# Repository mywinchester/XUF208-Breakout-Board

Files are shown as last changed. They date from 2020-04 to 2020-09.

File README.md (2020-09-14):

# XMOS XU(F)208 Breakout Board <!-- omit in toc -->

XMOS XU208/XUF208 series minimal system board with USB Type-C port, full XSYS debug port, all pin already breakout to edge of the board.

#### Table of Contents <!-- omit in toc -->

- [1. Image](#1-image)
- [2. Altium Libraries](#2-altium-libraries)
- [3. Shield](#3-shield)
- [4. About fabrication files](#4-about-fabrication-files)
  - [4.1. Gerber files](#41-gerber-files)
  - [4.2. NC drill files](#42-nc-drill-files)
- [5. Last](#5-last)

## 1. Image

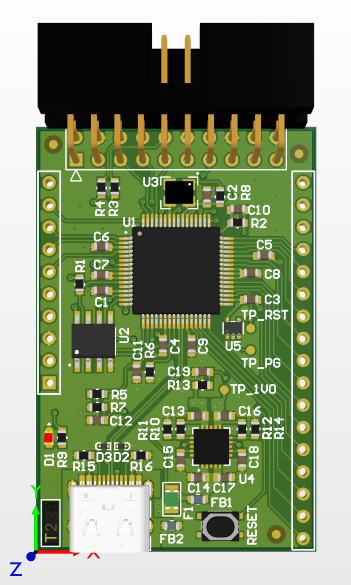
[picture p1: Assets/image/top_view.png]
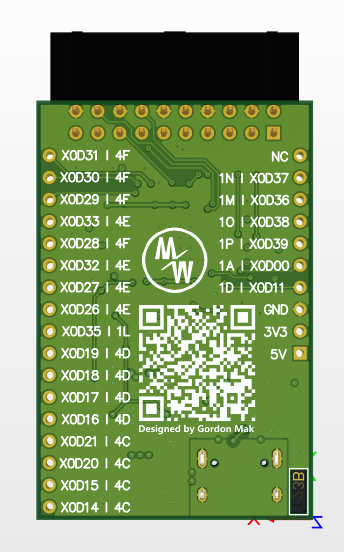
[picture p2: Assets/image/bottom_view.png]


## 2. Altium Libraries

All using components from [Altium-Components-Libraries](https://github.com/mywinchester/Altium-Components-Libraries), this is an open source project focus on refined component management. Classified components with 3D model, easy to use schematic with different package, and also using official recommended layout.

## 3. Shield

Now we have two shield for this breakout board:

- [XUF208-Clock-Board](https://github.com/mywinchester/XUF208-Clock-Board) : Clock generated board with CDCE913 PLL, with I2C interface. Clock output from Y1 pin.

- [XUF208-IO-Board](https://github.com/mywinchester/XUF208-IO-Board) : Four LEDs and four buttons board.

And there have a table for complete plan:

| XUF208-Breakout-Board | XUF208-Clock-Board | XUF208-DAC-Board | XUF208-ADC-Board | XUF208-SPDIF-Board | XUF208-IO-Board |
| :--- | :--- | :--- | :--- | :--- | :--- |
| X0D31(4F) | | | | | |
| X0D30(4F) | | | | | |
| X0D29(4F) | | | | | |
| X0D33(4E) | | | | | |
| X0D28(4F) | -> I2C_SCL | -> I2C_SCL | -> I2C_SCL | | |
| X0D32(4E) | | | | | |
| X0D27(4E) | | | | | |
| X0D26(4E) | <-> I2C_SDA | <-> I2C_SDA | <-> I2C_SDA | | |
| X0D35(1L) | <- MCLK | -> MCLK | -> MCLK | -> MCLK | |
| X0D19(4D) | | | | | <- BUTTON_1 |
| X0D18(4D) | | | | | <- BUTTON_2 |
| X0D17(4D) | | | | | <- BUTTON_3 |
| X0D16(4D) | | | | | <- BUTTON_4 |
| X0D21(4C) | | | | | -> LED_1 |
| X0D20(4C) | | | | | -> LED_2 |
| X0D15(4C) | | | | | -> LED_3 |
| X0D14(4C) | | | | | -> LED_4 |
| - | - | - | - | - | - |
| X0D37(1N) | | -> LRCLK | -> LRCLK | | |
| X0D36(1M) | | -> BCLK | -> BCLK | | |
| X0D38(1O) | | -> DIN | | | |
| X0D39(1P) | | | <-DOUT | | |
| X0D00(1A) | | | | <- S/PDIF_RX | |
| X0D11(1D) | | | | -> S/PDIF_TX | |

Note:

> ` -> ` means Input (for shield itself)  
> ` <- ` means Output (for shield itself)  
> ` <-> ` means Bidirectional (for shield itself)  
> ` - ` means Placeholder

## 4. About fabrication files

Folder Gerber include **gerber files** and **NC drill files**. If your manufacturer using other format or setting for fabrication files, you should not be use those files.

### 4.1. Gerber files

Exported with following settings:

- Unit: Inches
- Format: 2:5
- Output Layout: Plot all layers, except:
  - Mechanical 13
  - Mechanical 15
  - Mechanical 16
  - Top Pad Master
  - Buttom Pad Master
- Plot all used drill pairs
- Use software arcs
- other setting use default

Note:

> `Mechanical 1`(Gerber/XUF208_Breakout.GM1) for board shape.  
> `Mechanical 17`(Gerber/XUF208_Breakout.GM17) for describe impedance detail.

### 4.2. NC drill files

Exported with following settings:

- default

## 5. Last

Have fun with it :)

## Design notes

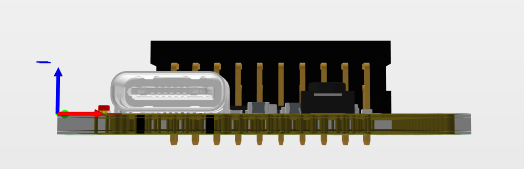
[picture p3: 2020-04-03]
Assets/image/front_view.png

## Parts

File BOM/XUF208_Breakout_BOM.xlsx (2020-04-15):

Quantity | Designator | Value | Description | Comment | LibRef | Footprint | Manufacturer Part Number
12 | C1, C2, C3, C4, C5, C6, C7, C8, C9, C10, C11, C19 | 100nF | Multilayer Ceramic Capacitors | MLCC | MLCC | CAP_0603 | CL10B104KB8NNNC
1 | C12 | 1uF | Multilayer Ceramic Capacitors | MLCC | MLCC | CAP_0603 | CL10A105KB8NNNC
4 | C13, C14, C16, C17 | 10uF | Multilayer Ceramic Capacitors | MLCC | MLCC | CAP_0603 | CL10A106MQ8NNNC
2 | C15, C18 | 10nF | Multilayer Ceramic Capacitors | MLCC | MLCC | CAP_0603 | CL10B103KB8NNNC
1 | D1 |  | LED Emitters | LED | LED | 0603_RED | 19-217/R6C-AL1M2VY/3T
2 | D2, D3 |  | ESD Protection Diode | ESD9B | ESD9B | SOD-923-2 | ESD9B5.0ST5G
1 | F1 |  | Fuses | Fuse | Fuse | 0805 | 0805L110SLYR
1 | FB1 | 300Ohms @ 100MHz | Ferrite Beads | Ferrite | Ferrite | IND_1608 | MMZ1608R301ATA00
1 | FB2 | 47Ohms @ 100MHz | Ferrite Beads | Ferrite | Ferrite | IND_1608 | BLM18BB470SN1D
1 | J1 |  | Universal Serial Bus (USB) I/O Receptacle, Type C, 2.0 | USB C RECEPTACLE(1) | USB C RECEPTACLE(1) | USB C RECEPTACLE 2(1) | TYPE-C-31-M-12
1 | J2 |  | 20-Pin Shrouded Header (IDC) Right Angle | DC3-20P | DC3-20P | IDC-20 (1) | Z-231012020106
1 | P1 |  | Header, 10-Pin | Header 10 | Header 10 | HDR1X10
1 | P2 |  | Header, 17-Pin | Header 17 | Header 17 | HDR1X17
1 | R1 | 1K | Chip Resistors | RES | RES | RC0603N | AC0603FR-071KL
1 | R2 | 4.7 | Chip Resistors | RES | RES | RC0603N | RC0603JR-074R7L
2 | R3, R4 | 33 | Chip Resistors | RES | RES | RC0603N | RC0603FR-0733RL
3 | R5, R8, R13 | 10K | Chip Resistors | RES | RES | RC0603N | RC0603FR-0710KL
1 | R6 | 43.2 | Chip Resistors | RES | RES | RC0603N | RC0603FR-0743R2L
1 | R7 | 47K | Chip Resistors | RES | RES | RC0603N | RC0603FR-0747KL
1 | R9 | 2K | Chip Resistors | RES | RES | RC0603N | RC0603FR-072KL
1 | R10 | 33.2K | Chip Resistors | RES | RES | RC0603N | RC0603FR-0733K2L
1 | R11 | 10.7K | Chip Resistors | RES | RES | RC0603N | AC0603FR-0710K7L
1 | R12 | 2.55K | Chip Resistors | RES | RES | RC0603N | AC0603FR-072K55L
1 | R14 | 10.2K | Chip Resistors | RES | RES | RC0603N | AC0603FR-0710K2L
2 | R15, R16 | 5.1K | Chip Resistors | RES | RES | RC0603N | RC0603FR-075K1L
1 | RESET1 |  | Switch | Tact Switch SPST | Tact Switch SPST | TS_SPST_W4.2XD3.2 | SKRPABE010
1 | U1 |  | xCORE Multicore Microcontroller, xCORE-200, USB, Single Tile, 8 Cores, 500MHz, 64TQFP | XUF208-256-TQ64 | XUF208-256-TQ64 | TQ64 | XUF208-256-TQ64
1 | U2 |  | 3V 16M-BIT SERIAL FLASH MEMORY WITH DUAL/QUAD SPI | W25Q16JV | W25Q16JV | SOIC-8_150MIL | W25Q16JVSNIQ
1 | U3 |  | SiTime Ultra Performance Oscillator | XO | XO | QFN_3225_4P | SiT8008AI-21-33N-24.000000D
1 | U4 |  | TPS7A87 Dual, 500-mA, Low-Noise (3.8 μVRMS), LDO Voltage Regulator | TPS7A87 | TPS7A87 | RTJ20 | TPS7A8701RTJT
1 | U5 |  | Single 2-Input AND Gate | MC74VHC1G08 | MC74VHC1G08 | SC-88A | MC74VHC1G08DFT1G

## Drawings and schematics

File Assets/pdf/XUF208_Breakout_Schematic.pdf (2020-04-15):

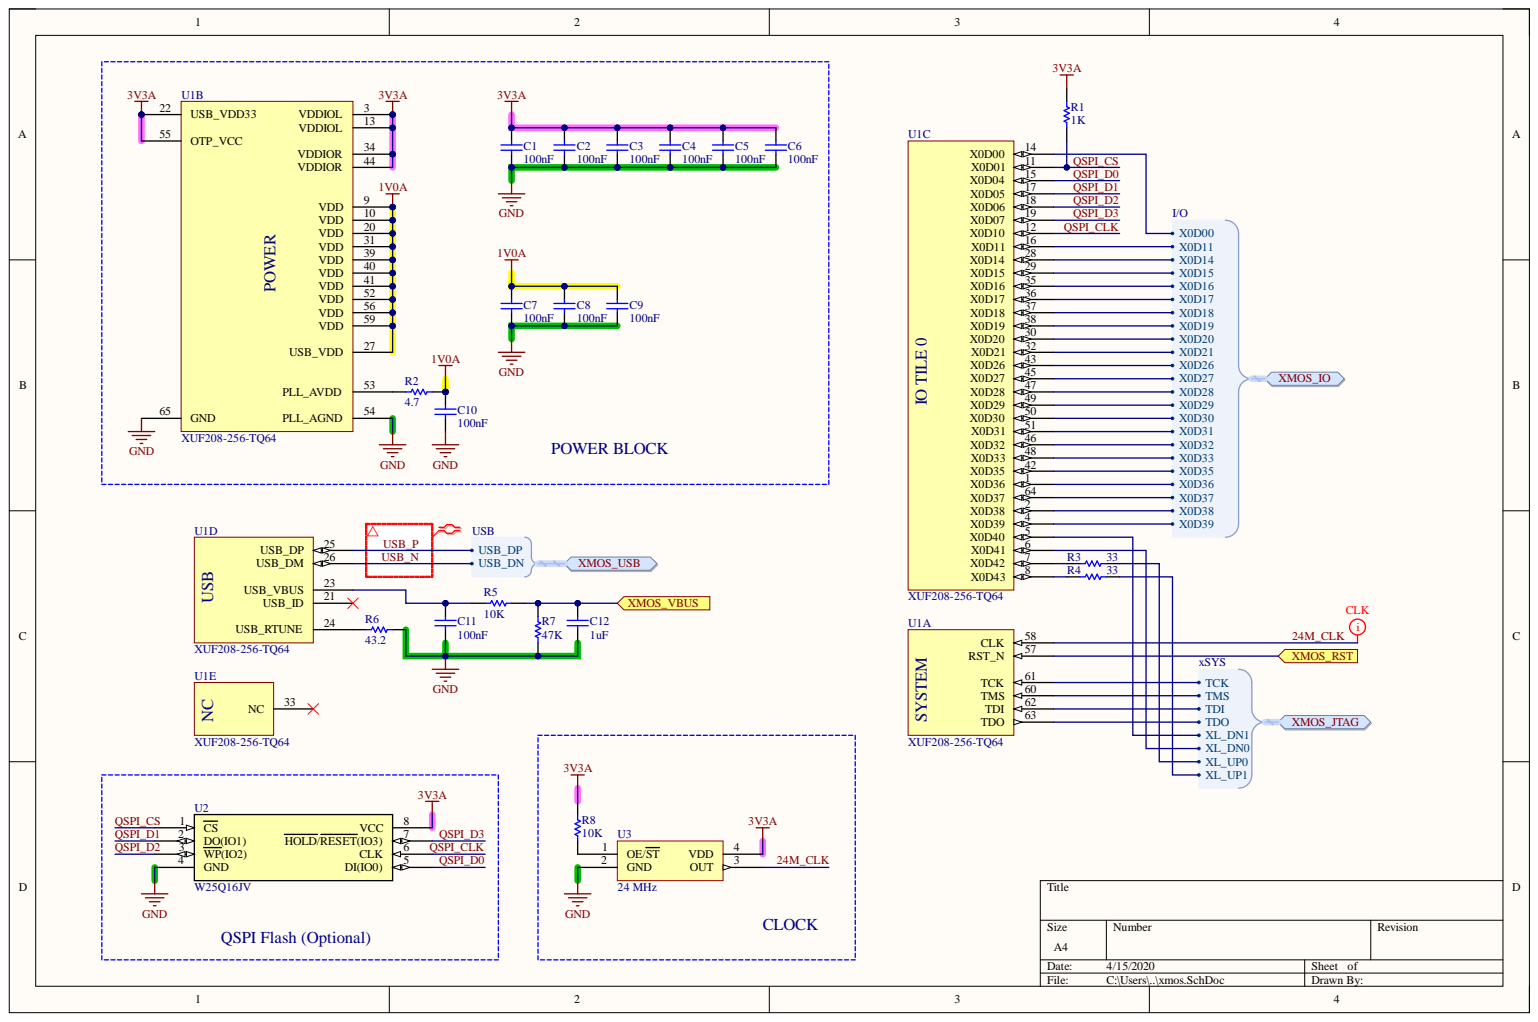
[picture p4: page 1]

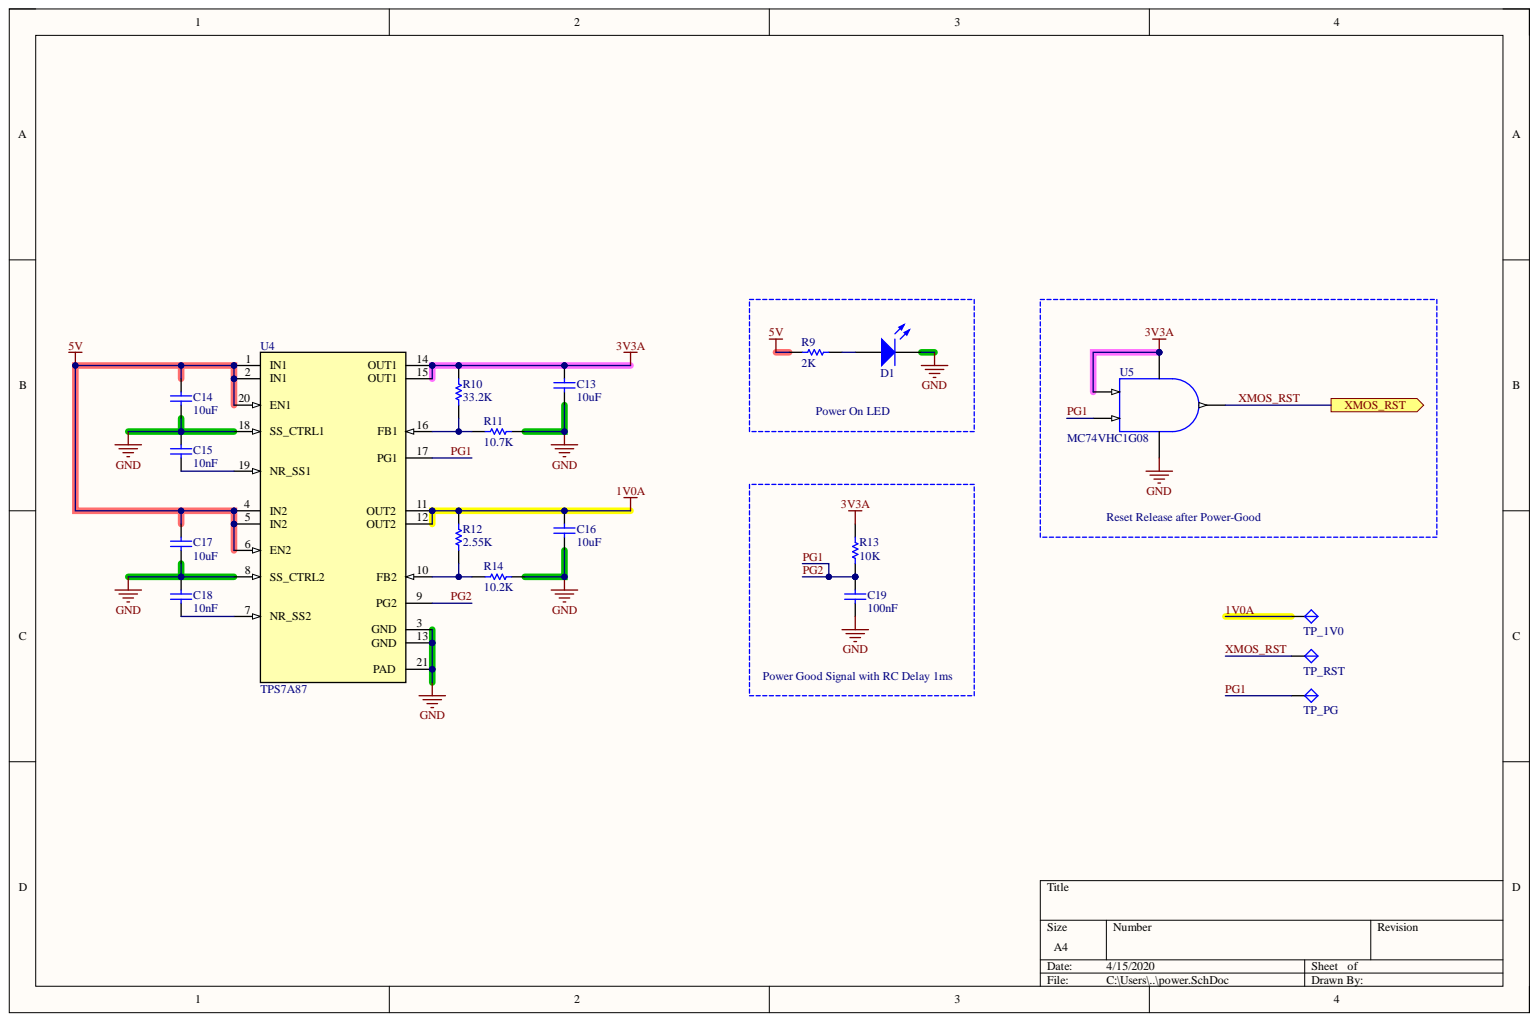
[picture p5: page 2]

Reset Release after Po

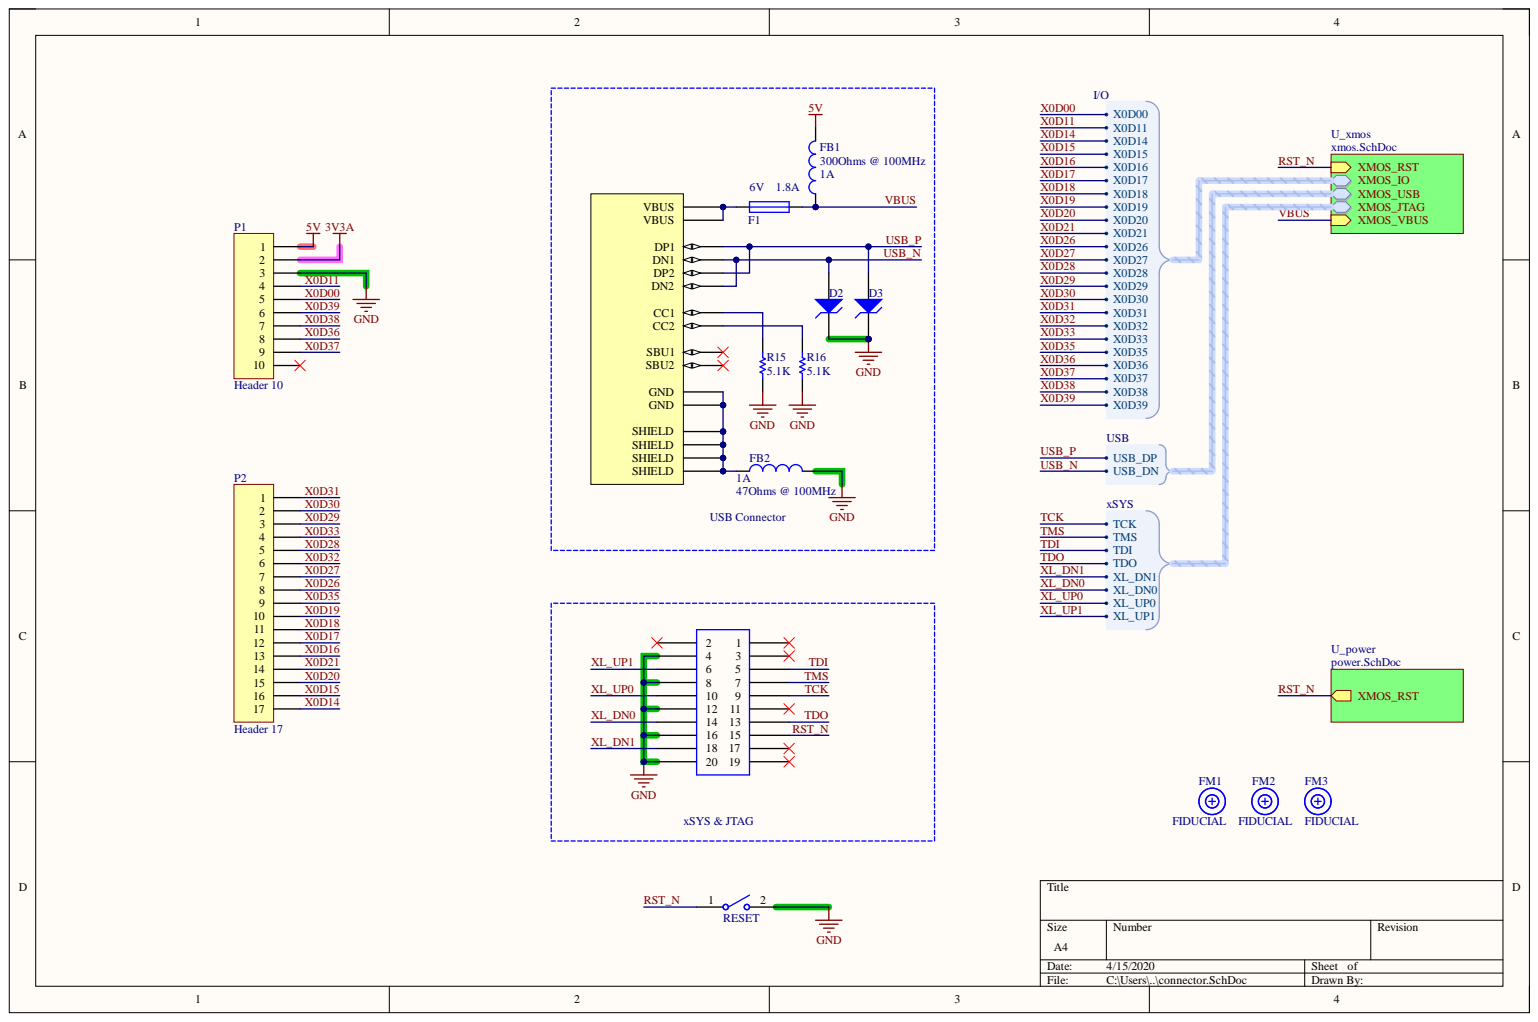
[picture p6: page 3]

USB_
TCK TMS TDI TDO XL_UP1 XL_UP0 XL_DN0 XL_DN1
TCK TMS TDI TDO XL_D

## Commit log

2020-03-05 Init repo
    [XUF208_Breakout.PcbDoc, XUF208_Breakout.PrjPcb, connector.SchDoc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]
2020-03-12 Add ESD diode for USB DP DN
    [connector.SchDoc]
2020-03-12 Upload Gerber and NC Drill files
    [XUF208_Breakout.GBL, XUF208_Breakout.GBO, XUF208_Breakout.GBP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]
2020-03-16 Upload schematic in pdf and Bill of Materials
    [XUF208_Breakout_BOM.xlsx]
2020-03-24 Fix 1V0 power-good voltage level error
    [connector.SchDoc, power.SchDoc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]
2020-03-24 Fix power LED value
    [XUF208_Breakout_BOM.xlsx, power.SchDoc]
2020-04-01 Major update:
    -VBUS add fuse
    -Remove R16 0Ohms jumper
    -Remove PG2 RC delay circuit
    -Optimization components place
    -Optimization trace
    [XUF208_Breakout.GBL, XUF208_Breakout.GBO, XUF208_Breakout.GBS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]
2020-04-03 Fix: Oscillator GND polygon and RST trace
    [XUF208_Breakout.GBL, XUF208_Breakout.GTL, XUF208_Breakout.GTS]
2020-04-03 Update: Multi optimization
    [XUF208_Breakout.GBL, XUF208_Breakout.GTL, XUF208_Breakout.GTO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]
2020-04-03 Update: Optimize polygon and component state
    [XUF208_Breakout.GBL, XUF208_Breakout.GTL, XUF208_Breakout.GTO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]
2020-04-03 Organize documents
    [XUF208_Breakout.GBL, XUF208_Breakout.GBO, XUF208_Breakout.GBP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]
2020-04-15 Add bypass capacitors for 3V3
    [XUF208_Breakout_BOM.xlsx, connector.SchDoc, power.SchDoc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]
2020-04-16 Fix: remove usb data trace stub
    Add designer silk
    [XUF208_Breakout.GBL, XUF208_Breakout.GBO, XUF208_Breakout.GTL]
2020-09-14 Rename readme file to upper case
